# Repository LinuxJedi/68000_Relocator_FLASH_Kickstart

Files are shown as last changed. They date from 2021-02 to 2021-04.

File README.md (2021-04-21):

# 68000 Relocator with FLASH based Kickstart
Forked from https://github.com/PR77/68000_Relocator_FLASH_Kickstart and the software and firmware have been modified as well as a GUI tool created.

It now supports two flashed kickstart ROMs and has a cleaner interface.

**NOTE:** If you are using FK 3.0 command line tool or FlashKickstart GUI tool you will need to use the 3.0 Xilinx firmware too. Otherwise hi/lo ROMs will be the mapped to the same address.

**NOTE 2:** With firmware version 3.4 onwards the the jumper now switches between motherboard and ROM bank 1 as the first ROM. Jumper off for motherboard, jumper on for board ROM1. You will need 39SF040 ROM chips to use 3.4 onwards.

**NOTE 3:** The hardware directory in this tree was a PoC and will not work. Please use PR77's board linked to in the GitHub link above.

# Overview
To allow for Flash Kickstart images to be mapped in the same address space as existing ROM Kickstart without the need to remove the existing ROM. This design is targeting an accelerated A500(+) system which also require a CPU relocation.

# Flashing new ROMs
It is recommended you use the included FlashKickstart GUI tool. To use this you may need to install the reqtools library in your LIBS: drive. If you are using Kickstart 1.3 this is available in the lib13 directory of the software, for 2.0 onwards use the version in libs20 directory.

You can then load "FlashKickstart" and you should see the window similar to below:

FlashKickstart

You need to erase the ROMs before flashing a new image. Erasing will clear both the flash ROM slots.

Erasing

You can then program with any ROM you wish. You should not use byte-swapped ROMs.

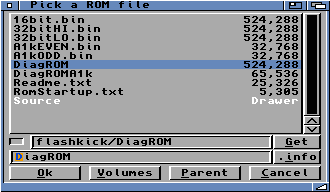
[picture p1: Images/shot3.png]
File browsing


Flashing

# Using the ROMs
In principle the operation is fairly simple. A CPLD is used to switch between the ROM Kickstart on the Motherboard or the two Flash Kickstart on the CPU Relocator. Switching is performed by an active /RESET (CTRL-A-A) without interruption for longer than 1 second. Shorter /RESET durations will simply just reset the Amiga. After a POR (Power On Reset) by default the Kickstart on the Motherboard will be used.

## ROM based Kickstart
When ROM Kickstart is being used, the hardware simply passed /AS to the Amiga Motherboard to allow GARY perform the address decode and chip select of the internal ROM. During this process, the Flash Kickstart is simply not used - except when programming. A Zorro II space of 1MB is requested and allocated by the Amiga which maps to the Flash devices.

When programming the Flash devices, access is via this Zorro II space. Programming of the Flash devices can only be performed when ROM Kickstart is being used.

## FLASH based Kickstart
When Flash Kickstart is being used, the hardware simply blocks /AS to the Amiga Motherboard and the CPLD will perform the operation of Flash device control. As /AS is not asserted on the Amiga Motherboard, and therefore no GARY decode, the Relocator CPLD will then also assert the /DTACK after placing data on the bus - this is needed to complete the CPU cycle.

### Overlay Interception
When Flash Kickstart mode is being used, the CPLD will also intercept the overlay of the Kickstart in the 0x000000 memory space until the first access to the custom chip register is performed. This ensures the correct SP and IP initialisation is performed directly after POR (Power On Reset) as the Flash Kickstart is used by default.

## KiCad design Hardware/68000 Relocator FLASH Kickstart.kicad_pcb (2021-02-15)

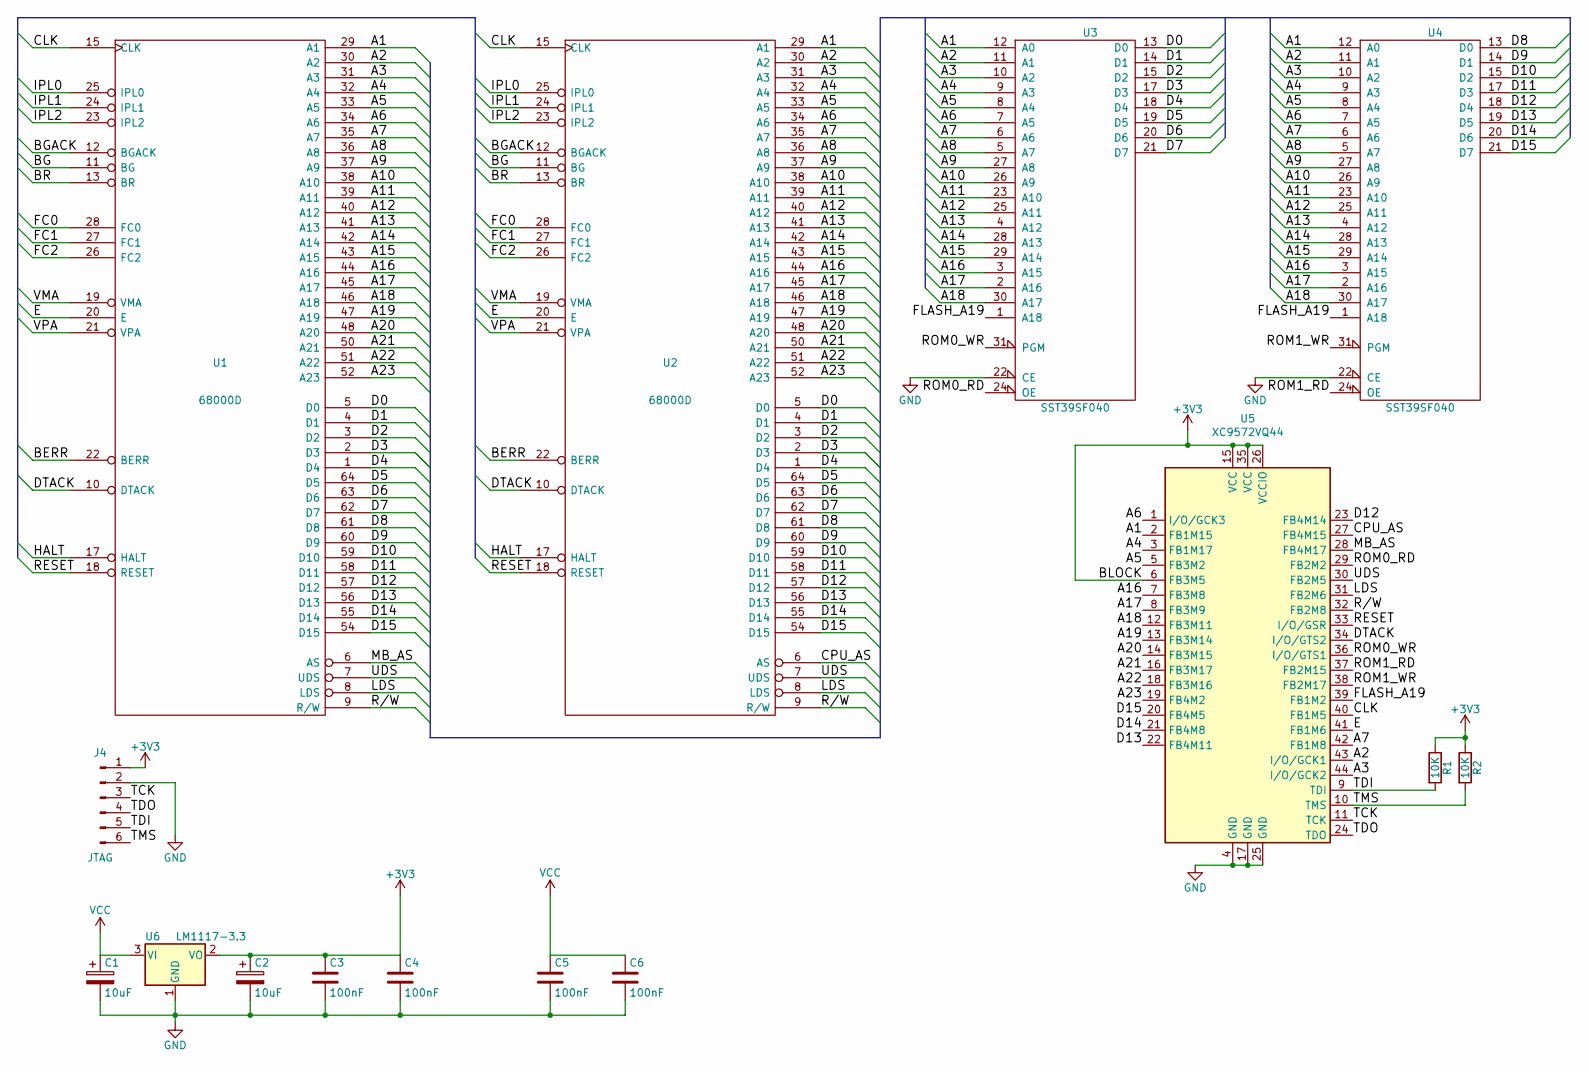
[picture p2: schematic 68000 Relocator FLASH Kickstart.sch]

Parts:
C1, C2: 10uF; CP_Tantalum_Case-B_EIA-3528-21_Hand
C3, C4, C5, C6: 100nF; C_0805_HandSoldering
J4: JTAG; Pin_Header_Straight_1x06_Pitch2.54mm
R1, R2: 10K; R_0805_HandSoldering
U1, U2: 68000D; DIP-64_W22.86mm_Socket_LongPads
U3, U4: SST39SF040; DIP-32_W15.24mm_Socket
U5: XC9572VQ44; TQFP-44_10x10mm_Pitch0.8mm
U6: LM1117-3.3; SOT-223-3_TabPin2

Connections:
+3V3: C2.1, C3.1, C4.1, J4.1, R1.1, R2.1, U5.6 (FB3M5), U5.15 (VCC), U5.26 (VCCIO), U5.35 (VCC), U6.2 (VO)
/A1: U1.29 (A1), U2.29 (A1), U3.12 (A0), U4.12 (A0), U5.2 (FB1M15)
/A2: U1.30 (A2), U2.30 (A2), U3.11 (A1), U4.11 (A1), U5.43 (I/O/GCK1)
/A3: U1.31 (A3), U2.31 (A3), U3.10 (A2), U4.10 (A2), U5.44 (I/O/GCK2)
/A4: U1.32 (A4), U2.32 (A4), U3.9 (A3), U4.9 (A3), U5.3 (FB1M17)
/A5: U1.33 (A5), U2.33 (A5), U3.8 (A4), U4.8 (A4), U5.5 (FB3M2)
/A6: U1.34 (A6), U2.34 (A6), U3.7 (A5), U4.7 (A5), U5.1 (I/O/GCK3)
/A7: U1.35 (A7), U2.35 (A7), U3.6 (A6), U4.6 (A6), U5.42 (FB1M8)
/A8: U1.36 (A8), U2.36 (A8), U3.5 (A7), U4.5 (A7)
/A9: U1.37 (A9), U2.37 (A9), U3.27 (A8), U4.27 (A8)
/A10: U1.38 (A10), U2.38 (A10), U3.26 (A9), U4.26 (A9)
/A11: U1.39 (A11), U2.39 (A11), U3.23 (A10), U4.23 (A10)
/A12: U1.40 (A12), U2.40 (A12), U3.25 (A11), U4.25 (A11)
/A13: U1.41 (A13), U2.41 (A13), U3.4 (A12), U4.4 (A12)
/A14: U1.42 (A14), U2.42 (A14), U3.28 (A13), U4.28 (A13)
/A15: U1.43 (A15), U2.43 (A15), U3.29 (A14), U4.29 (A14)
/A16: U1.44 (A16), U2.44 (A16), U3.3 (A15), U4.3 (A15), U5.7 (FB3M8)
/A17: U1.45 (A17), U2.45 (A17), U3.2 (A16), U4.2 (A16), U5.8 (FB3M9)
/A18: U1.46 (A18), U2.46 (A18), U3.30 (A17), U4.30 (A17), U5.12 (FB3M11)
/A19: U1.47 (A19), U2.47 (A19), U5.13 (FB3M14)
/A20: U1.48 (A20), U2.48 (A20), U5.14 (FB3M15)
/A21: U1.50 (A21), U2.50 (A21), U5.16 (FB3M17)
/A22: U1.51 (A22), U2.51 (A22), U5.18 (FB3M16)
/A23: U1.52 (A23), U2.52 (A23), U5.19 (FB4M2)
/BERR: U1.22 (BERR), U2.22 (BERR)
/BG: U1.11 (BG), U2.11 (BG)
/BGACK: U1.12 (BGACK), U2.12 (BGACK)
/BR: U1.13 (BR), U2.13 (BR)
/CLK: U1.15 (CLK), U2.15 (CLK), U5.40 (FB1M5)
/CPU_AS: U2.6 (AS), U5.27 (FB4M15)
/D0: U1.5 (D0), U2.5 (D0), U3.13 (D0)
/D1: U1.4 (D1), U2.4 (D1), U3.14 (D1)
/D2: U1.3 (D2), U2.3 (D2), U3.15 (D2)
/D3: U1.2 (D3), U2.2 (D3), U3.17 (D3)
/D4: U1.1 (D4), U2.1 (D4), U3.18 (D4)
/D5: U1.64 (D5), U2.64 (D5), U3.19 (D5)
/D6: U1.63 (D6), U2.63 (D6), U3.20 (D6)
/D7: U1.62 (D7), U2.62 (D7), U3.21 (D7)
/D8: U1.61 (D8), U2.61 (D8), U4.13 (D0)
/D9: U1.60 (D9), U2.60 (D9), U4.14 (D1)
/D10: U1.59 (D10), U2.59 (D10), U4.15 (D2)
/D11: U1.58 (D11), U2.58 (D11), U4.17 (D3)
/D12: U1.57 (D12), U2.57 (D12), U4.18 (D4), U5.23 (FB4M14)
/D13: U1.56 (D13), U2.56 (D13), U4.19 (D5), U5.22 (FB4M11)
/D14: U1.55 (D14), U2.55 (D14), U4.20 (D6), U5.21 (FB4M8)
/D15: U1.54 (D15), U2.54 (D15), U4.21 (D7), U5.20 (FB4M5)
/DTACK: U1.10 (DTACK), U2.10 (DTACK), U5.34 (I/O/GTS2)
/E: U1.20 (E), U2.20 (E), U5.41 (FB1M6)
/FC0: U1.28 (FC0), U2.28 (FC0)
/FC1: U1.27 (FC1), U2.27 (FC1)
/FC2: U1.26 (FC2), U2.26 (FC2)
/FLASH_A19: U3.1 (A18), U4.1 (A18), U5.39 (FB1M2)
/HALT: U1.17 (HALT), U2.17 (HALT)
/IPL0: U1.25 (IPL0), U2.25 (IPL0)
/IPL1: U1.24 (IPL1), U2.24 (IPL1)
/IPL2: U1.23 (IPL2), U2.23 (IPL2)
/LDS: U1.8 (LDS), U2.8 (LDS), U5.31 (FB2M6)
/MB_AS: U1.6 (AS), U5.28 (FB4M17)
/R/W: U1.9 (R/W), U2.9 (R/W), U5.32 (FB2M8)
/RESET: U1.18 (RESET), U2.18 (RESET), U5.33 (I/O/GSR)
/ROM0_RD: U3.24 (OE), U5.29 (FB2M2)
/ROM0_WR: U3.31 (PGM), U5.36 (I/O/GTS1)
/ROM1_RD: U4.24 (OE), U5.37 (FB2M15)
/ROM1_WR: U4.31 (PGM), U5.38 (FB2M17)
/TCK: J4.3, U5.11 (TCK)
/TDI: J4.5, R1.2, U5.9 (TDI)
/TDO: J4.4, U5.24 (TDO)
/TMS: J4.6, R2.2, U5.10 (TMS)
/UDS: U1.7 (UDS), U2.7 (UDS), U5.30 (FB2M5)
/VMA: U1.19 (VMA), U2.19 (VMA)
/VPA: U1.21 (VPA), U2.21 (VPA)
GND: C1.2, C2.2, C3.2, C4.2, C5.2, C6.2, J4.2, U1.16 (GND), U1.53 (GND), U2.16 (GND), U2.53 (GND), U3.16 (GND), U3.22 (CE), U4.16 (GND), U4.22 (CE), U5.4 (GND), U5.17 (GND), U5.25 (GND), U6.1 (GND)
VCC: C1.1, C5.1, C6.1, U1.14 (VCC), U1.49 (VCC), U2.14 (VCC), U2.49 (VCC), U3.32 (VCC), U4.32 (VCC), U6.3 (VI)

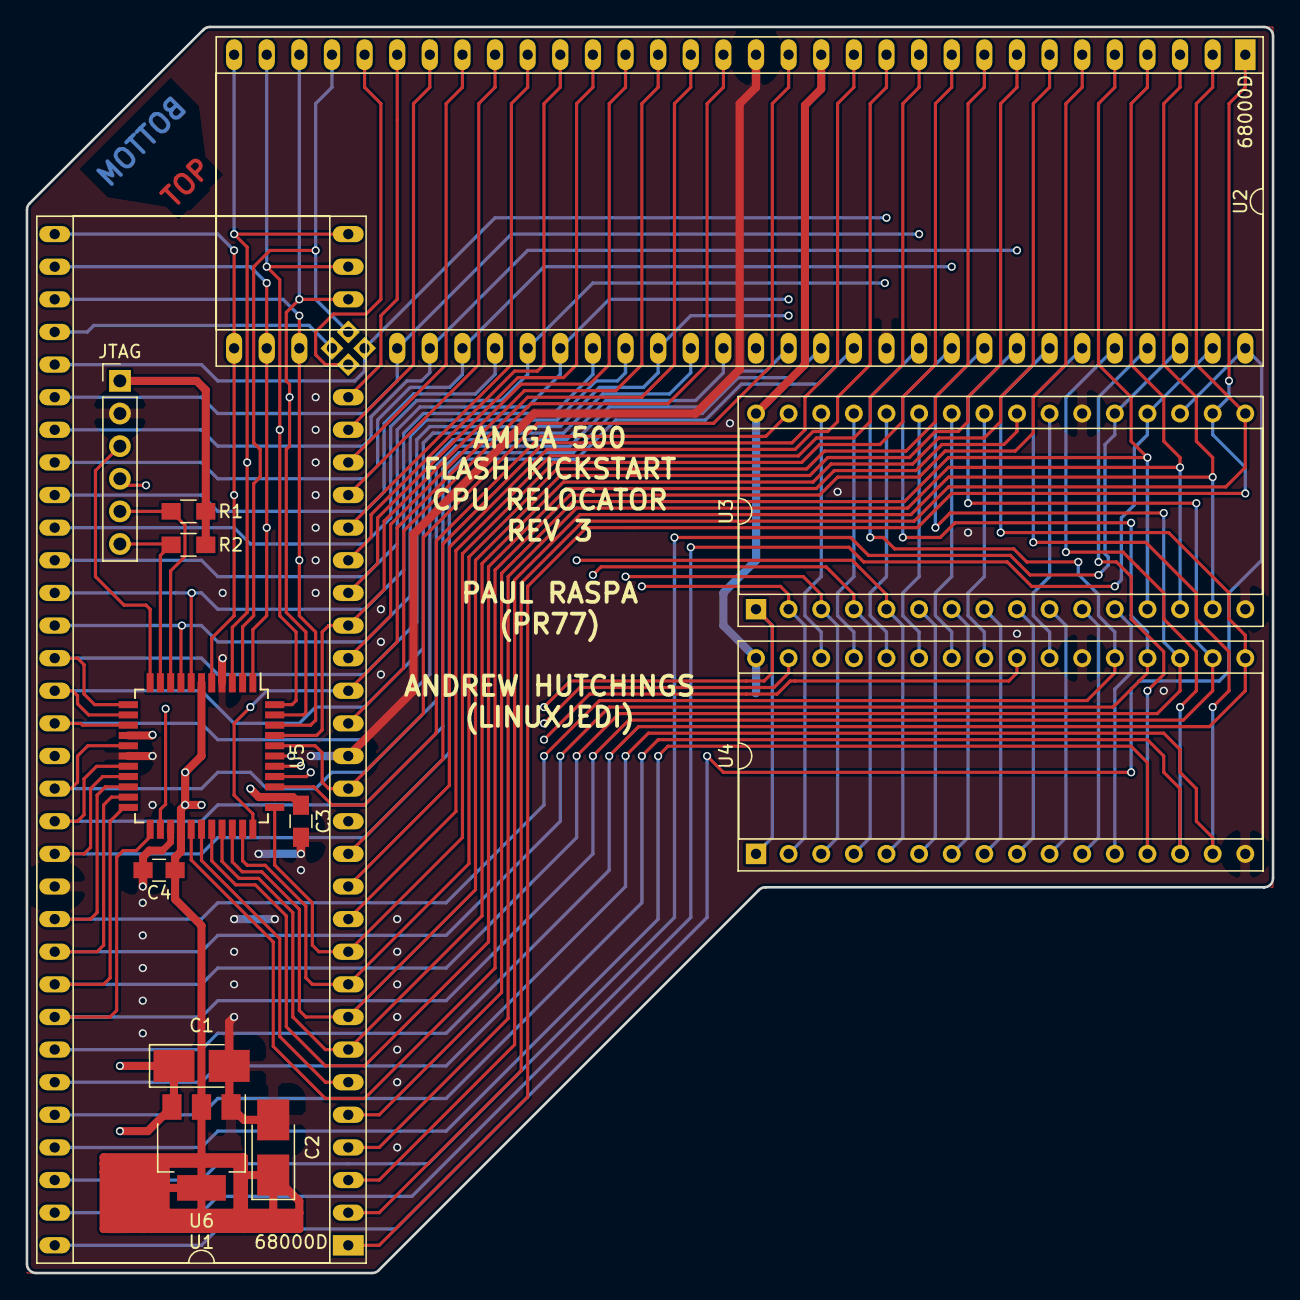
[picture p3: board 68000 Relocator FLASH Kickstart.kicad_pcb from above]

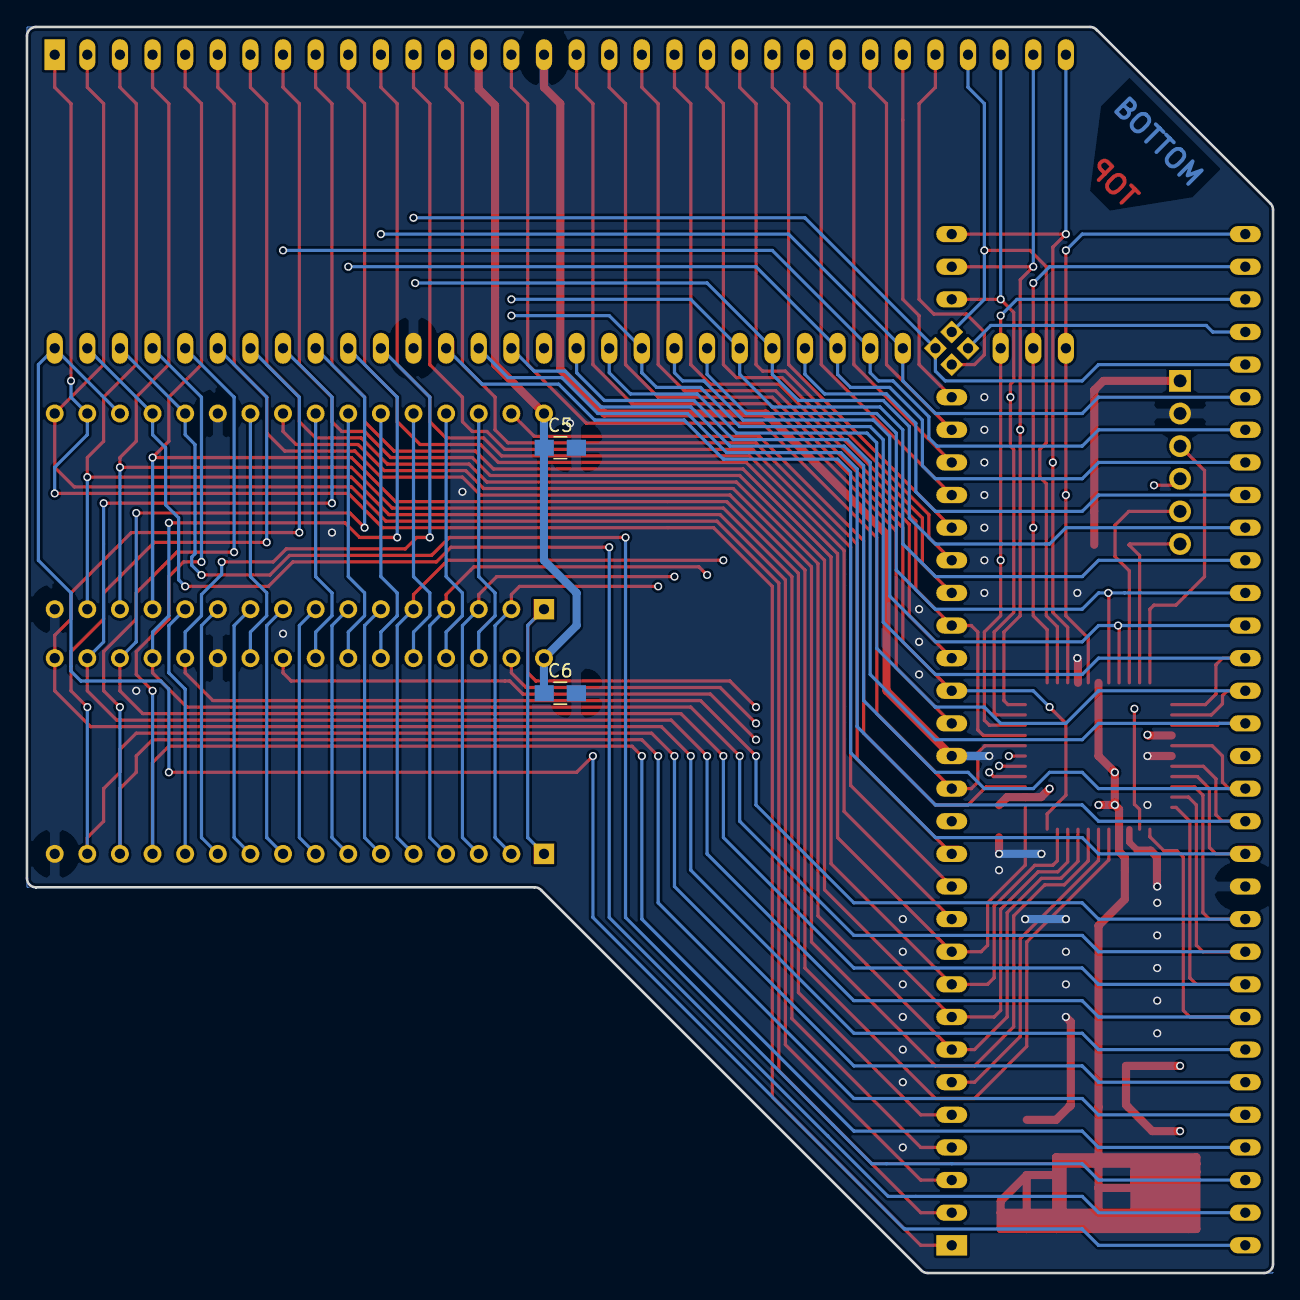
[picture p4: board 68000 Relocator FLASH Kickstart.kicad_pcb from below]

Board: 4 copper layers, 97.0 x 97.0 mm, 15 parts (2 on the bottom side), 73 nets.

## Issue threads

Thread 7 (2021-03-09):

Compatibility issues

LinuxJedi, 2021-03-09:
This issue is to track compatibility issues with other hardware, sub-issues will likely be created to work on solving any.

LinuxJedi, 2021-03-09:
### Wicher 508i

I've had a report that the Wicher is blocking the autoconfig process on the relocator card from happening. This would make sense when FastRAM is in use as it uses the entire 8MB Zorro II space and a few extra spaces. But even with that disabled the autoconfig process does not happen. I don't have one of these boards so I don't know the process it takes or how to resolve this.

LinuxJedi, 2021-03-09:
### SukkoPera's 8MB FastRAM Expansion

This FastRAM expansion basically consumes the entire autoconfig process, blocking anything else from using it. As a workaround you can put this RAM board below the relocator, then when using the motherboard ROM the FastRAM is disabled. But when booting from a flash ROM the RAM is available.

A "fix" may be to add a shim board between the CPU and the RAM board and add a virtual CFGIN/CFGOUT by trapping / controlling AS to each board.

LinuxJedi, 2021-04-08:
### Amiga 2000 rev 6

I've had a report of reboot loops in the rev 6 Amiga 2000 even with the 3.03 firmware. No clue why yet because rev 4.4 works fine.

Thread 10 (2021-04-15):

Handle situation where board is told to shut up

LinuxJedi, 2021-04-15:
If the board autoconfiged but was told to shut up the software assumes it has one ROM visible when it doesn't

Closed 2021-04-21.

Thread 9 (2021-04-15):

Long initial reset on PiStorm boot

LinuxJedi, 2021-04-15:
PiStorm effectively does a really long reset which causes immediate ROM switch for us. Need to support reset held down on power on.

Closed 2021-04-21.

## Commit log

2021-02-15 V 1.1 of GUI and Rev 3 PCB
    GUI:
    * No longer requires entire ROM to be flashed to be loaded into RAM
    PCB:
    * Removed tick
    * Made PCB a little smaller
    * Removed unneeded jumper
    * Moved caps for flash chips to underside (to solder chips directly)
    * Move JTAG down slightly so it can be used with a CPU board
    * Other cleanups
    [68000 Relocator FLASH Kickstart.kicad_pcb, 68000 Relocator FLASH Kickstart.sch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]
2021-02-24 Switch to VBCC
    GCC compilation was causing a weird issue where when starting the GUI
    by double-clicking the icon in WB 1.3 the entire system would
    immediately crash hard. But it worked fine when executing from a shell.
    Switched to VBCC which appears to have solved the problem. Also some
    minor code cleanups.
2021-03-05 Cleanups and new features
    Logic:
    * Make the autoconfig easier to read
    * Add versioning as the serial to the autoconfig
    CLI:
    * Show board version number in information
    * Show board version number in "About"
    * Fix block erase code
    * Now erases a single ROM before flashing a new one
    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
2021-03-10 Board can work outside the 8MB Zorro II range
    Toggle the bit to do this
2021-04-21 Fixes from PiStorm testing
    Firmware
    * Jumper now determines which ROM will boot first (off for Motherboard).
    Firmware now only works with two-ROMs
    * Fix issue where held reset on first boot switches ROM (PiStorm boot)
    GUI Software
    * If autoconfig failed then disable ROM flashing with appropriate
    message
